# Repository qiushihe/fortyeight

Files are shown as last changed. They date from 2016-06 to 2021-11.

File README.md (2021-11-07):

# The FortyEight

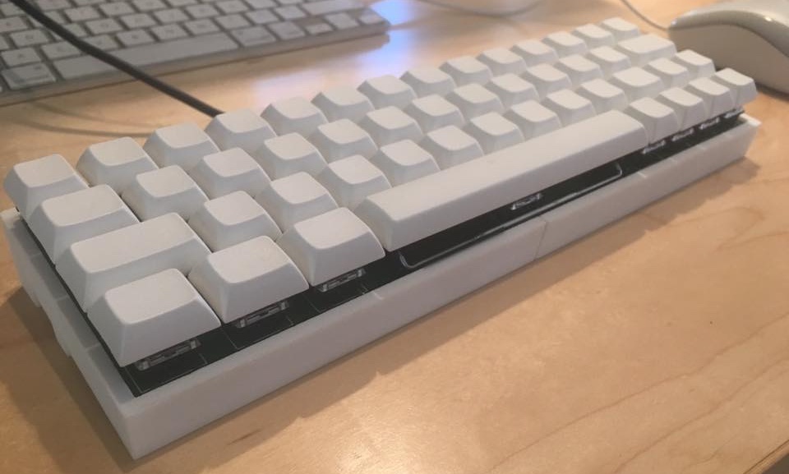
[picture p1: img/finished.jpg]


### Layout

Source: [layout.kbd.json](layout/default.kbd.json)

Online: [keyboard-layout-editor.com](http://www.keyboard-layout-editor.com/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'kb%20kb-Line-Start-End'%3E%3C%2F%2Fi%3E&_c=%23cccccc%3B&=%0AA&=%0AS&=%0AD&_n:true%3B&=%0AF&=%0AG&=%0AH&_n:true%3B&=%0AJ&=%0AK&=%0AL&_t=%230099cc%0A%23000000%0A%0A%0A%0A%0A%23000000%3B&=%0A%2F%3B%0A%0A%0A%0A%0A%2F:&=%0A'%0A%0A%0A%0A%0A%22&_c=%23bbbbbb&t=%230099cc%0A%0A%0A%23000000&w:1.75%3B&=%0A%0A%0A%E2%8F%8E%3B&@_t=%230099cc%0A%23000000&f:3&w:1.75%3B&=%E2%87%AA%0A%E2%87%A7&_c=%23cccccc%3B&=%0AZ&=%0AX&=%0AC&=%0AV&=%0AB&=%0AN&=%0AM&_t=%230099cc%0A%23000000%0A%0A%0A%0A%0A%23000000%3B&=%0A,%0A%0A%0A%0A%0A%3C&=%0A.%0A%0A%0A%0A%0A%3E&_f:3&w:1.25%3B&=%3Ci%20class%2F='fa%20fa-play'%3E%3C%2F%2Fi%3E%2F%2F%3Ci%20class%2F='fa%20fa-pause'%3E%3C%2F%2Fi%3E%0A%2F%2F%0A%0A%0A%0A%0A%3F&_c=%23bbbbbb&t=%230099cc&f:3%3B&=%3Ci%20class%2F='fa%20fa-volume-up'%3E%3C%2F%2Fi%3E%0A%0A%0A%0A%0A%0A%0A%0A%0A%E2%96%B2&_c=%230099cc&t=%23ffffff&f:3%3B&=Fn2%3B&@_c=%23bbbbbb&t=%23000000&a:5&w:1.25%3B&=%0A%E2%8C%83&_t=%230099cc%0A%0A%0A%0A%0A%0A%0A%0A%0A%0A%23000000&a:4&f:3&w:1.25%3B&=%E2%8E%87%0A%0A%0A%0A%0A%0A%0A%0A%0A%0A%E2%8C%A5&_t=%23000000&a:5&w:1.25%3B&=%0A%E2%8C%98&_c=%23cccccc&a:7&w:6.25%3B&=&_c=%23cc0000&t=%23ffffff&a:4&f:3%3B&=%0A%0AFn1&_c=%23bbbbbb&t=%230099cc&f:3%3B&=%3Ci%20class%2F='fa%20fa-fast-backward'%3E%3C%2F%2Fi%3E%0A%0A%0A%0A%0A%0A%0A%0A%0A%E2%97%80%EF%B8%8E&_f:3%3B&=%3Ci%20class%2F='fa%20fa-volume-down'%3E%3C%2F%2Fi%3E%0A%0A%0A%0A%0A%0A%0A%0A%0A%E2%96%BC&_f:3%3B&=%3Ci%20class%2F='fa%20fa-fast-forward'%3E%3C%2F%2Fi%3E%0A%0A%0A%0A%0A%0A%0A%0A%0A%E2%96%B6%EF%B8%8E)

**Default layout:**

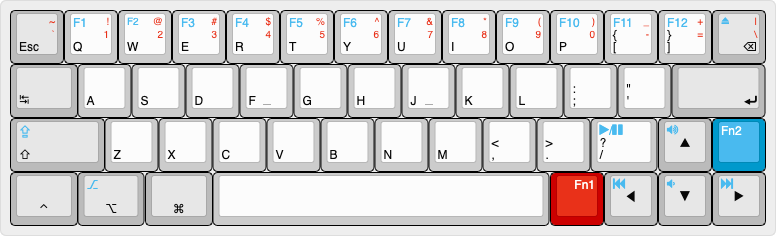
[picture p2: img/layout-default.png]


**Alternative right-hand-side layout:**



### PCB

Source: [Gerber Drill](Gerber_Drill)

Online: https://easyeda.com/qiushihe/FortyEight-06QK2We7p

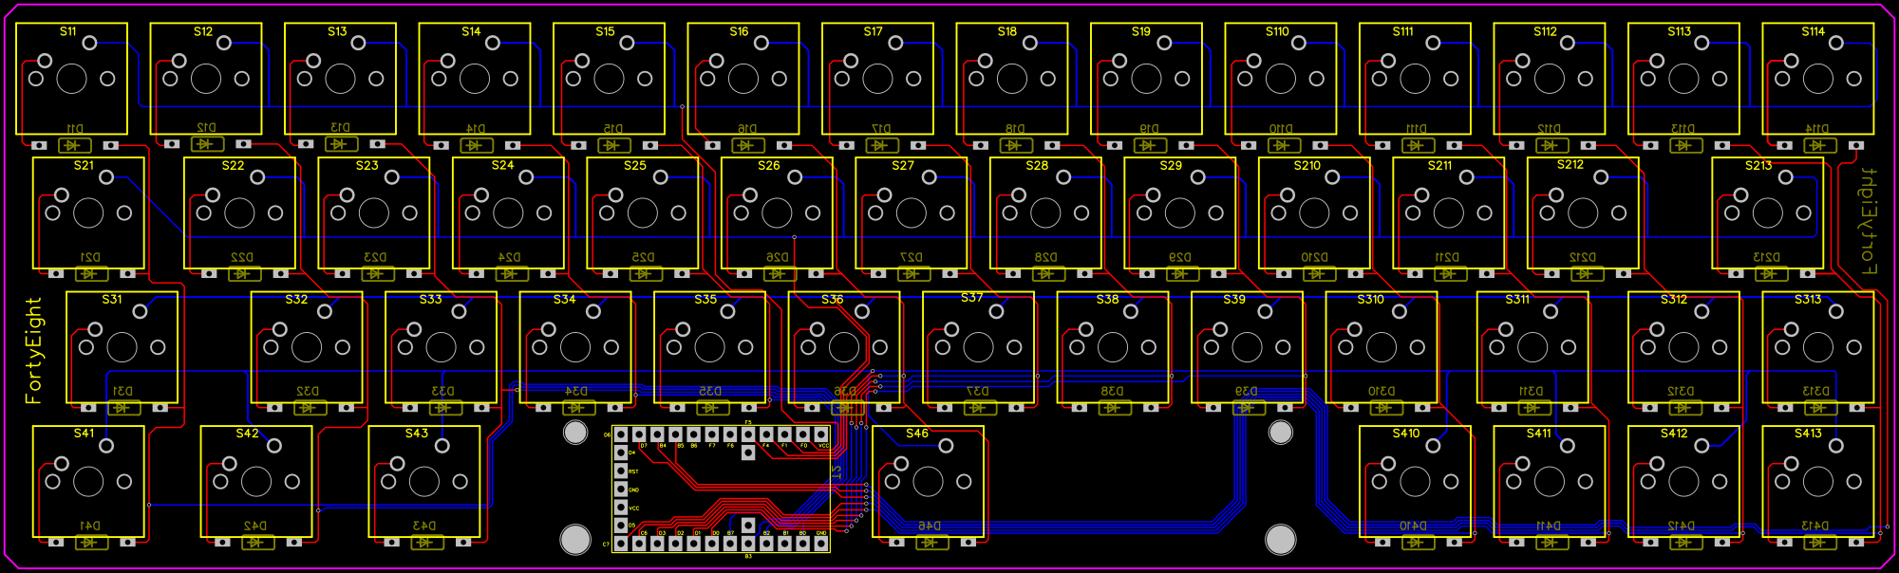
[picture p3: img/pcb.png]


For the diodes use 1N4148.

### Firmware

Firmware source: [firmware.ino](firmware/firmware.ino)

Onboard controller is a [Teensy 2.0](https://www.pjrc.com/store/teensy.html).

Firmware is programmed with [Arduino IDE](https://www.arduino.cc/en/Main/Software),
[Teensyduino](https://www.pjrc.com/teensy/teensyduino.html) and
[Teensy Loader](https://www.pjrc.com/teensy/loader.html).

### Case

STL: [FortyEight Case V2](case/FortyEight-Case-V2.stl)

Online: https://cad.onshape.com/documents/feea34d0a9c6b57c6ef59bb9/w/05d58c69e3a7dbc46aef47f1/e/c60b2f45b17ec6026b843ee2

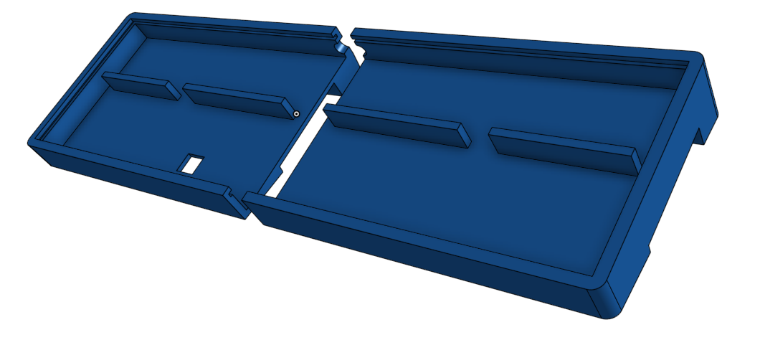
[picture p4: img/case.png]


### Switches and Keycaps

**Switches**

Any cherry (or compatible) will do.

Switch dimension: 15.6mm / 15.6mm

**Keycaps:**

Supplier: http://pimpmykeyboard.com/blank-key-packs/dsa

* 1.00u x 40
* 1.25u x 5
* 1.75u x 2
* 6.25u x 1

... where 1u == 19.05mm.

It's best to use DSA or SA keycaps because DCS doesn't have certain length for the specific
row some keys need to be on. For DCS the alternative solution is to get everything from R1.

### Spacebar and Stabilizer

Only need one: 6.25u for the spacebar

**Cherry stabilizer specification:**

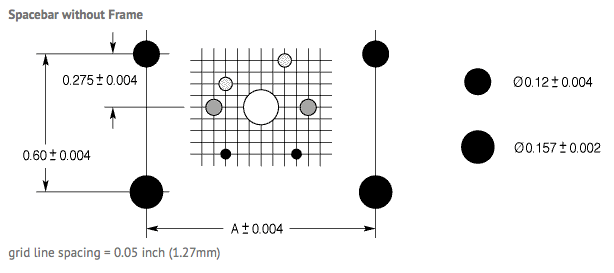
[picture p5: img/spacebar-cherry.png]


Supplier: https://www.originativeco.com/products/cherry-pcb-mounted-stabilizer

**Costar stabilizer specification:**

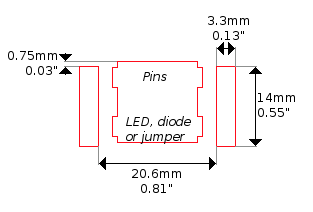
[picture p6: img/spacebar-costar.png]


**Keycap specification:**

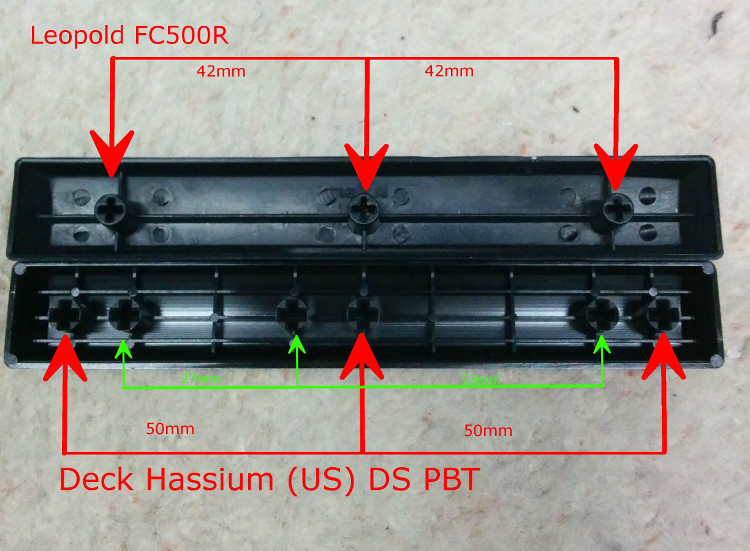
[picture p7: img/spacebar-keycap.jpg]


### Keycap Stickers

http://www.4keyboard.com

### Bill of Materials

* Switches: ~$50
* PCB: ~$45
* Teensy: ~$35
* Keycaps: ~$100
* Diodes: ~$10
* Stabilizer: ~$20
* Case: ~$160
* **Total: ~$420**

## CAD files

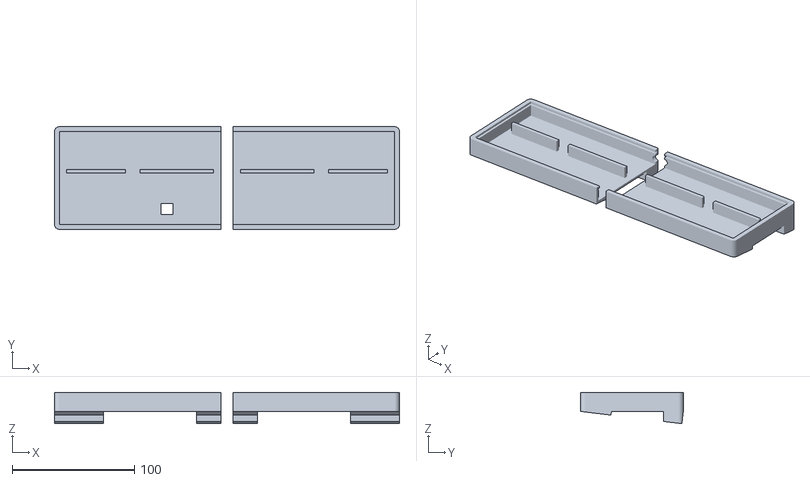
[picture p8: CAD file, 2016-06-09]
case/FortyEight-Case-V2.stl
282.0 x 84.0 x 25.6

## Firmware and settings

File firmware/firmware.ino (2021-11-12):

// Note pin input/output designations:
//
// * Currently:                      Row pins are used as input pins and column pins are used as
//                                   output pins. This means that when checking for key activation
//                                   status, signal is sent to a particular column pin, then loop
//                                   over all the row pins to check which keys on that column are
//                                   pressed down.
//
// * However:                        The above logic is actually the opposite of what it's supposed
//                                   to be. Accordingly to the PCB design, column pins should be
//                                   used as input and row pins should be used as output (see diols
//                                   direction on the PCB).
//
// * The Reason:                     For using row and column pins for the opposite purposes they
//                                   are designed for is because when soldering diols I soldered
//                                   them all in the reverse direction (lol).
//
// * The "By-Design" Implementation: Is to use column pins as input pins and row pins as output pins.
//                                   And when checking for key activation status, signal should be
//                                   sent to a particular row pin, then loop over all the column pins
//                                   to check which keys on that row are pressed down.
//
// * TODO:                           Implement support for specifying pin input/output designation
//                                   mode so it would be easier to switch between "signal row check
//                                   columns" vs. "signal column check rows".

#define LOG_TO_SERIAL false

#define PIN_ROW1 PIN_F0
#define PIN_ROW2 PIN_F1
#define PIN_ROW3 PIN_F4
#define PIN_ROW4 PIN_F5

#define PIN_COLUMN1 PIN_B0
#define PIN_COLUMN2 PIN_B1
#define PIN_COLUMN3 PIN_B2
#define PIN_COLUMN4 PIN_B3
#define PIN_COLUMN5 PIN_B7
#define PIN_COLUMN6 PIN_D0
#define PIN_COLUMN7 PIN_D1
#define PIN_COLUMN8 PIN_D2
#define PIN_COLUMN9 PIN_D3
#define PIN_COLUMN10 PIN_C6
#define PIN_COLUMN11 PIN_C7
#define PIN_COLUMN12 PIN_D7
#define PIN_COLUMN13 PIN_B4
#define PIN_COLUMN14 PIN_B5

#define KEY_STATE_DOWN 1
#define KEY_STATE_UP 0

#define LAYER_ZERO 0
#define LAYER_ONE 1
#define LAYER_TWO 2

// The Fn1 and Fn2 keys are not mapped to any acutal key code so their real values are just `0`.
// But still define macros for them so they're easier to spot in the key maps below.
#define KEY_FN1 0
#define KEY_FN2 0

unsigned int layers[3][4][14] = {
  {
    {KEY_ESC, KEY_Q, KEY_W, KEY_E, KEY_R, KEY_T, KEY_Y, KEY_U, KEY_I, KEY_O, KEY_P, KEY_LEFT_BRACE, KEY_RIGHT_BRACE, KEY_BACKSPACE},
    {KEY_TAB, KEY_A, KEY_S, KEY_D, KEY_F, KEY_G, KEY_H, KEY_J, KEY_K, KEY_L, KEY_SEMICOLON, KEY_QUOTE, KEY_ENTER, 0},
    {KEY_LEFT_SHIFT, KEY_Z, KEY_X, KEY_C, KEY_V, KEY_B, KEY_N, KEY_M, KEY_COMMA, KEY_PERIOD, KEY_SLASH, KEY_UP, KEY_FN2, 0},
    {KEY_LEFT_CTRL, KEY_LEFT_ALT, KEY_LEFT_GUI, 0, 0, KEY_SPACE, 0, 0, 0, KEY_FN1, KEY_LEFT, KEY_DOWN, KEY_RIGHT, 0}
  },
  {
    {KEY_TILDE, KEY_1, KEY_2, KEY_3, KEY_4, KEY_5, KEY_6, KEY_7, KEY_8, KEY_9, KEY_0, KEY_MINUS, KEY_EQUAL, KEY_BACKSLASH},
    {0, 0, 0, 0, 0, 0, 0, 0, 0, 0, 0, 0, 0, 0},
    {KEY_LEFT_SHIFT, 0, 0, 0, 0, 0, 0, 0, 0, 0, 0, 0, KEY_FN2, 0},
    {KEY_LEFT_CTRL, KEY_LEFT_ALT, KEY_LEFT_GUI, 0, 0, KEY_SPACE, 0, 0, 0, KEY_FN1, 0, 0, 0, 0}
  },
  {
    {0, KEY_F1, KEY_F2, KEY_F3, KEY_F4, KEY_F5, KEY_F6, KEY_F7, KEY_F8, KEY_F9, KEY_F10, KEY_F11, KEY_F12, KEY_MEDIA_EJECT},
    {0, 0, 0, 0, 0, 0, 0, 0, 0, 0, 0, 0, 0, 0},
    {KEY_CAPS_LOCK, 0, 0, 0, 0, 0, 0, 0, 0, 0, KEY_MEDIA_PLAY_PAUSE, KEY_MEDIA_VOLUME_INC, KEY_FN2, 0},
    {KEY_LEFT_CTRL, KEY_LEFT_ALT, KEY_LEFT_GUI, 0, 0, KEY_SPACE, 0, 0, 0, KEY_FN1, KEY_MEDIA_PREV_TRACK, KEY_MEDIA_VOLUME_DEC, KEY_MEDIA_NEXT_TRACK, 0}
  }
};

unsigned int keyState[4][14] = {
  {0, 0, 0, 0, 0, 0, 0, 0, 0, 0, 0, 0, 0, 0},
  {0, 0, 0, 0, 0, 0, 0, 0, 0, 0, 0, 0, 0, 0},
  {0, 0, 0, 0, 0, 0, 0, 0, 0, 0, 0, 0, 0, 0},
  {0, 0, 0, 0, 0, 0, 0, 0, 0, 0, 0, 0, 0, 0}
};

unsigned int keyStateWas[4][14] = {
  {0, 0, 0, 0, 0, 0, 0, 0, 0, 0, 0, 0, 0, 0},
  {0, 0, 0, 0, 0, 0, 0, 0, 0, 0, 0, 0, 0, 0},
  {0, 0, 0, 0, 0, 0, 0, 0, 0, 0, 0, 0, 0, 0},
  {0, 0, 0, 0, 0, 0, 0, 0, 0, 0, 0, 0, 0, 0}
};

unsigned int keyLayerWas[4][14] = {
  {0, 0, 0, 0, 0, 0, 0, 0, 0, 0, 0, 0, 0, 0},
  {0, 0, 0, 0, 0, 0, 0, 0, 0, 0, 0, 0, 0, 0},
  {0, 0, 0, 0, 0, 0, 0, 0, 0, 0, 0, 0, 0, 0},
  {0, 0, 0, 0, 0, 0, 0, 0, 0, 0, 0, 0, 0, 0}
};

unsigned int getLayer(unsigned int state[4][14]) {
  unsigned int layer = LAYER_ZERO;
  if (state[3][9] == KEY_STATE_DOWN) layer = LAYER_ONE;
  if (state[2][12] == KEY_STATE_DOWN) layer = LAYER_TWO;
  return layer;
}

unsigned int getMediaKey(unsigned int key) {
  if (key == KEY_MEDIA_PLAY_PAUSE) return KEY_MEDIA_PLAY_PAUSE;
  if (key == KEY_MEDIA_PREV_TRACK) return KEY_MEDIA_PREV_TRACK;
  if (key == KEY_MEDIA_NEXT_TRACK) return KEY_MEDIA_NEXT_TRACK;
  if (key == KEY_MEDIA_VOLUME_INC) return KEY_MEDIA_VOLUME_INC;
  if (key == KEY_MEDIA_VOLUME_DEC) return KEY_MEDIA_VOLUME_DEC;
  if (key == KEY_MEDIA_EJECT) return KEY_MEDIA_EJECT;
  return 0;
}

unsigned int getModifierKey(unsigned int key) {
  if (key == KEY_LEFT_SHIFT || key == KEY_RIGHT_SHIFT) return MODIFIERKEY_SHIFT;
  if (key == KEY_LEFT_CTRL || key == KEY_RIGHT_CTRL) return MODIFIERKEY_CTRL;
  if (key == KEY_LEFT_ALT || key == KEY_RIGHT_ALT) return MODIFIERKEY_ALT;
  if (key == KEY_LEFT_GUI || key == KEY_RIGHT_GUI) return MODIFIERKEY_GUI;
  return 0;
}

bool isKeyDown(unsigned int row, unsigned int column) {
  int rowPin = 0;
  if (row == 1) rowPin = PIN_ROW1;
  if (row == 2) rowPin = PIN_ROW2;
  if (row == 3) rowPin = PIN_ROW3;
  if (row == 4) rowPin = PIN_ROW4;

  // A pin is considered "on" (i.e. it's associated with a switch that is pressed down) if
  // the pin's signal is "low". So here we use `!` to check.
  return !digitalRead(rowPin);
}

void sendKeyDown(unsigned int layer, unsigned int row, unsigned int column) {
  unsigned int key = layers[layer][row - 1][column - 1];
  unsigned int modifier = getModifierKey(key);
  unsigned int media = getMediaKey(key);

  if (media) {
    Keyboard.set_media(media);
    Keyboard.send_now();
  } else if (modifier) {
    Keyboard.press(modifier);
  } else if (key) {
    Keyboard.press(key);
  }
}

void sendKeyUp(unsigned int layer, unsigned int row, unsigned int column) {
  unsigned int key = layers[layer][row - 1][column - 1];
  unsigned int modifier = getModifierKey(key);
  unsigned int media = getMediaKey(key);

  if (media) {
    Keyboard.set_media(0);
    Keyboard.send_now();
  } else if (modifier) {
    Keyboard.release(modifier);
  } else if (key) {
    Keyboard.release(key);
  }
}

void activateColumn(unsigned int column) {
  // Setting a line to "high" indicates the line is "off".
  // So here we turn off the lines for all columns except the given column.
  if (column != 1) digitalWrite(PIN_COLUMN1, HIGH);
  if (column != 2) digitalWrite(PIN_COLUMN2, HIGH);
  if (column != 3) digitalWrite(PIN_COLUMN3, HIGH);
  if (column != 4) digitalWrite(PIN_COLUMN4, HIGH);
  if (column != 5) digitalWrite(PIN_COLUMN5, HIGH);
  if (column != 6) digitalWrite(PIN_COLUMN6, HIGH);
  if (column != 7) digitalWrite(PIN_COLUMN7, HIGH);
  if (column != 8) digitalWrite(PIN_COLUMN8, HIGH);
  if (column != 9) digitalWrite(PIN_COLUMN9, HIGH);
  if (column != 10) digitalWrite(PIN_COLUMN10, HIGH);
  if (column != 11) digitalWrite(PIN_COLUMN11, HIGH);
  if (column != 12) digitalWrite(PIN_COLUMN12, HIGH);
  if (column != 13) digitalWrite(PIN_COLUMN13, HIGH);
  if (column != 14) digitalWrite(PIN_COLUMN14, HIGH);

  // Setting a line to "low" indicates the line is "on".
  // So here we only turn on the line for the given column.
  switch (column) {
    case 1: digitalWrite(PIN_COLUMN1, LOW); break;
    case 2: digitalWrite(PIN_COLUMN2, LOW); break;
    case 3: digitalWrite(PIN_COLUMN3, LOW); break;
    case 4: digitalWrite(PIN_COLUMN4, LOW); break;
    case 5: digitalWrite(PIN_COLUMN5, LOW); break;
    case 6: digitalWrite(PIN_COLUMN6, LOW); break;
    case 7: digitalWrite(PIN_COLUMN7, LOW); break;
    case 8: digitalWrite(PIN_COLUMN8, LOW); break;
    case 9: digitalWrite(PIN_COLUMN9, LOW); break;
    case 10: digitalWrite(PIN_COLUMN10, LOW); break;
    case 11: digitalWrite(PIN_COLUMN11, LOW); break;
    case 12: digitalWrite(PIN_COLUMN12, LOW); break;
    case 13: digitalWrite(PIN_COLUMN13, LOW); break;
    case 14: digitalWrite(PIN_COLUMN14, LOW); break;
  }
}

void setup() {
  // Set pins for rows as input pins.
  // This means from this program, we can determine if these pins are on or off.
  pinMode(PIN_ROW1, INPUT_PULLUP);
  pinMode(PIN_ROW2, INPUT_PULLUP);
  pinMode(PIN_ROW3, INPUT_PULLUP);
  pinMode(PIN_ROW4, INPUT_PULLUP);

  // Set pins for columns as output pins.
  // This means from this program, we can manipulate if these pins are on or off.
  pinMode(PIN_COLUMN1, OUTPUT);
  pinMode(PIN_COLUMN2, OUTPUT);
  pinMode(PIN_COLUMN3, OUTPUT);
  pinMode(PIN_COLUMN4, OUTPUT);
  pinMode(PIN_COLUMN5, OUTPUT);
  pinMode(PIN_COLUMN6, OUTPUT);
  pinMode(PIN_COLUMN7, OUTPUT);
  pinMode(PIN_COLUMN8, OUTPUT);
  pinMode(PIN_COLUMN9, OUTPUT);
  pinMode(PIN_COLUMN10, OUTPUT);
  pinMode(PIN_COLUMN11, OUTPUT);
  pinMode(PIN_COLUMN12, OUTPUT);
  pinMode(PIN_COLUMN13, OUTPUT);
  pinMode(PIN_COLUMN14, OUTPUT);

#if LOG_TO_SERIAL
  // Start serial mode.
  Serial.begin(9600);
  // Enable serial output.
  pinMode(11, OUTPUT);
#endif

  // Start keyboard mode.
  Keyboard.begin();
}

void loop() {
  unsigned int curRow = 0;
  unsigned int curCol = 0;

  // Loop over each column ...
  for (curCol = 1; curCol <= 14; curCol++) {
    // ... and turn off all columns except the current column.
    activateColumn(curCol);

    // This 1ms delay, together with the 1ms delay at the end of this function are important for
    // seemingly stopping an issue from happening where key strokes would ramdonly repeat. While
    // the actual cause of the issue is still unknown, having these delays nonetheless helps.
    delay(1);

    // ... then loop over each row in the current column.
    for (curRow = 1; curRow <= 4; curRow++) {
      // Update key down/up state.
      keyState[curRow - 1][curCol - 1] = isKeyDown(curRow, curCol) ? KEY_STATE_DOWN : KEY_STATE_UP;

      // Determine the current layer based on Fn key states.
      unsigned int layer = getLayer(keyState);

      // If the key was down ...
      if (keyStateWas[curRow - 1][curCol - 1] == KEY_STATE_DOWN) {
        // ... and still down ...
        if (keyState[curRow - 1][curCol - 1] == KEY_STATE_DOWN) {
          // ... then do nothing (no need to send "press" signal again).
        }
        // ... but is no longer down ...
        else {
          // ... then send the "release" signal ...
          sendKeyUp(keyLayerWas[curRow - 1][curCol - 1], curRow, curCol);

#if LOG_TO_SERIAL
          Serial.print("Up:   l");
          Serial.print(keyLayerWas[curRow - 1][curCol - 1]);
          Serial.print(" / r");
          Serial.print(curRow);
          Serial.print(" / c");
          Serial.print(curCol);
          Serial.println();
#endif

          // ... and clear the previous states.
          keyStateWas[curRow - 1][curCol - 1] = KEY_STATE_UP;
          keyLayerWas[curRow - 1][curCol - 1] = LAYER_ZERO;
        }
      }
      // If the key was up ...
      else {
        // ... but the key is now down ...
        if (keyState[curRow - 1][curCol - 1] == KEY_STATE_DOWN) {
          // ... then send the "press" signal ...
          sendKeyDown(layer, curRow, curCol);

#if LOG_TO_SERIAL
          Serial.print("Down: l");
          Serial.print(layer);
          Serial.print(" / r");
          Serial.print(curRow);
          Serial.print(" / c");
          Serial.print(curCol);
          Serial.println();
#endif

          // ... and update key states.
          keyStateWas[curRow - 1][curCol - 1] = KEY_STATE_DOWN;
          keyLayerWas[curRow - 1][curCol - 1] = layer;
        }
        // ... and the key is still up ...
        else {
          // ... then do nothing.
        }
      }
    }
  }

  // This 1ms delay, together with the 1ms delay above are important for seemingly stopping
  // an issue from happening where key strokes would ramdonly repeat. While the actual cause
  // of the issue is still unknown, having these delays nonetheless helps.
  delay(1);
}

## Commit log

2016-06-09 Update case
    [FortyEight Case.obj, FortyEight-Case-V2.stl, FortyEight.FCStd]
2021-11-09 Add inter-loop and inter-column 1ms delays to fix random key dupes issue
    [firmware.ino]
